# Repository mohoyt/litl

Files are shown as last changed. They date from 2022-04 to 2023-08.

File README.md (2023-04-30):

# litl
Litl is an easy to build 40% keyboard using only through hole components. It uses a separate microcontroller (like the Pro Micro or Elite C) to enable flexibility in connectivity and to further simplify the soldering experience (no more tricksy USB ports).

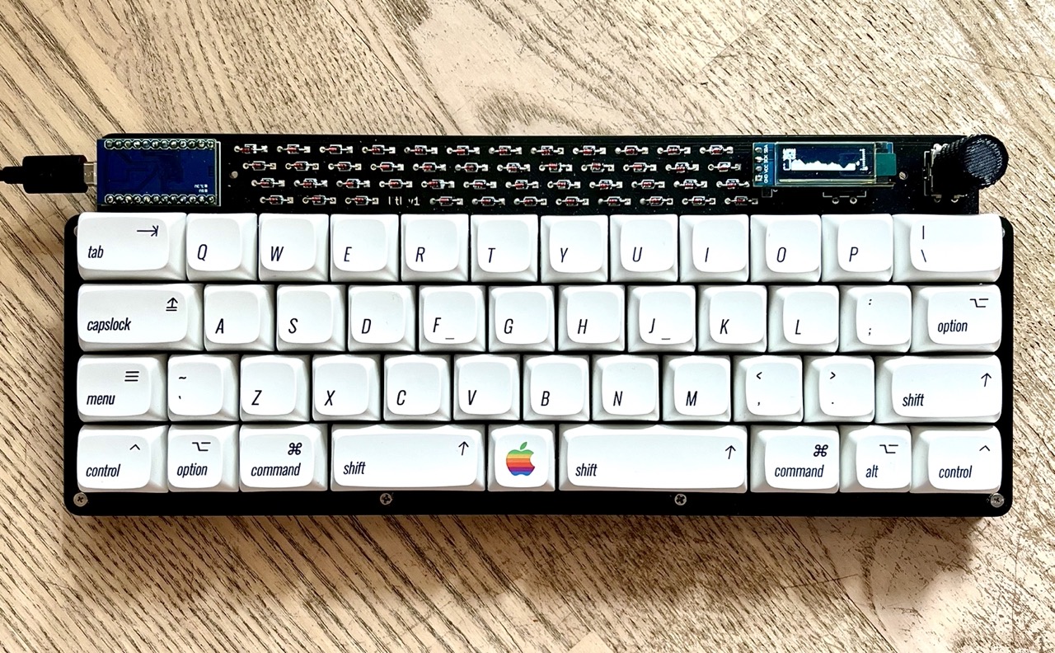
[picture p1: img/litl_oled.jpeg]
litl


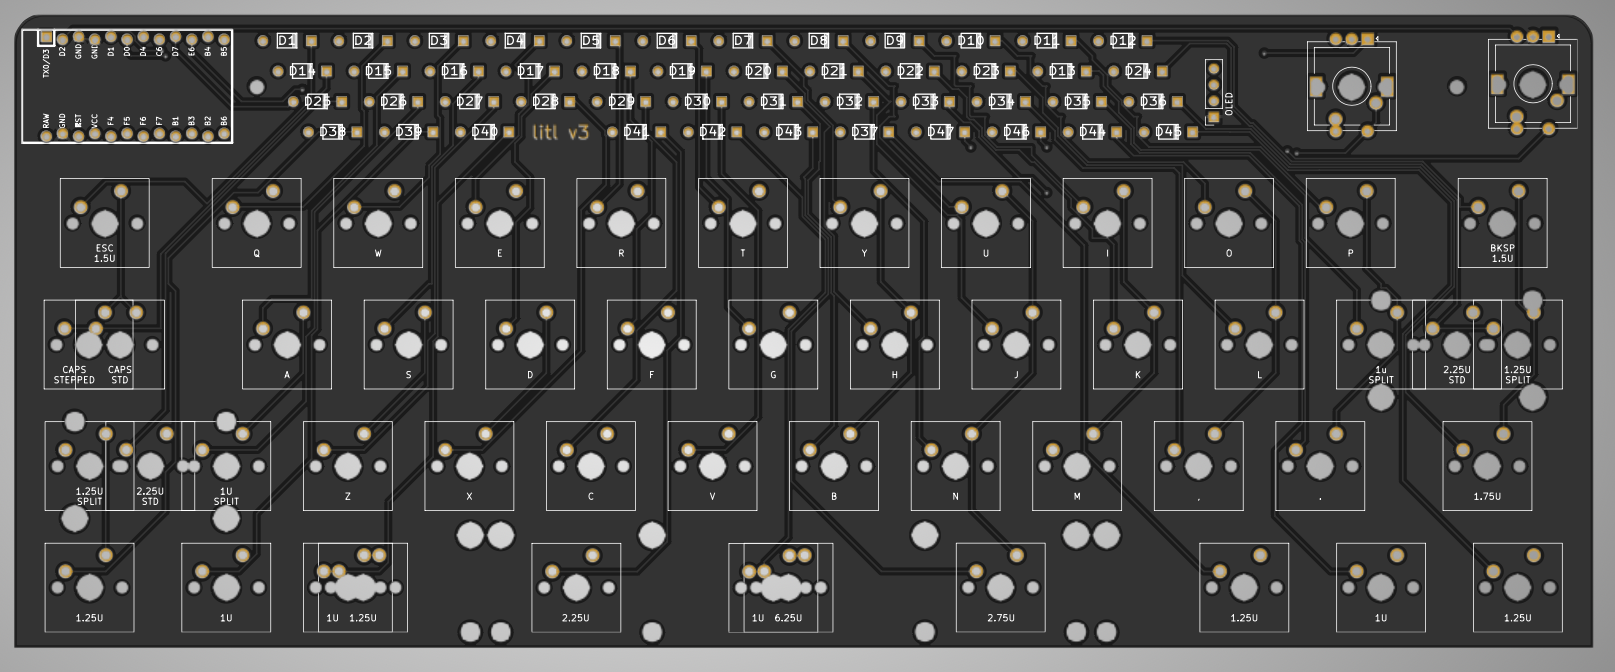
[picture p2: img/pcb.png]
litl pcb


[License](LICENSE)

Litl is licensed under the [Creative Commons Attribution-NonCommercial 4.0 International license](https://creativecommons.org/licenses/by-nc/4.0/). This design as it stands in this repository may be freely reproduced, modified, and manufactured for PERSONAL USE ONLY and may not be reproduced in physical form for public sale. 

Litl kits are available for sale at [sthlmkb.com](https://sthlmkb.com)

## Features
* Only through hole components for easy soldering
* Separate microcontroller using Pro micro, Elite C, Nice! Nano or equivalent footprint. So micro USB, USB-C or Bluetooth are all options!
* 1 or 2 rotary encoders
* OLED screen (though only 1 rotary encoder is possible if using OLED)
* Multiple layout options including split space (2.25u + 1u + 2.75u), split left shift (1.25u + 1u), split enter (1u + 1.25u) and stepped capslock ([layout](http://www.keyboard-layout-editor.com/##@_name=litl&author=mohoyt;&@_x:10.75&c=#82e0f5;&=Enc%202&_x:0.25&w:2.25;&=OLED&_x:0.25&c=#cccccc;&=Enc;&@_y:0.25&x:2.5&w:1.5;&=Esc&=Q&=W&=E&=R&=T&=Y&=U&=I&=O&=P&_w:1.5;&=Back%3Cbr%3ESpace;&@_c=#ebbebe&w:1.25&w2:1.75&l:true;&=Tab&_x:1.25&w:1.75;&=Tab&_c=#cccccc;&=A&=S&=D&=F&=G&=H&=J&=K&=L&_c=#aee6cb&w:2.25;&=Enter;&@_c=#dfe6ba&w:2.25;&=Shift&_x:0.25&w:1.25;&=Shift&=%60%0A~&_c=#cccccc;&=Z&=X&=C&=V&=B&=N&=M&=%3C%0A,&=%3E%0A.&_w:1.75;&=Shift;&@_x:2.5&w:1.25;&=Ctrl&=Alt&_c=#a8abed&w:1.25;&=Cmd&_a:7&w:2.25;&=&_a:4;&=Super&_a:7&w:2.75;&=&_c=#cccccc&a:4&w:1.25;&=Cmd&=Alt&_w:1.25;&=Ctrl;&@_y:0.25&x:4.75&c=#a8abed;&=Cmd&_a:7&w:6.25;&=&_x:1.25&c=#aee6cb&a:4;&='%0A%22&_w:1.25;&=Enter"))
* Open and visible components (in the style of Plaid, Romac etc)
* Simple and flexible case options 

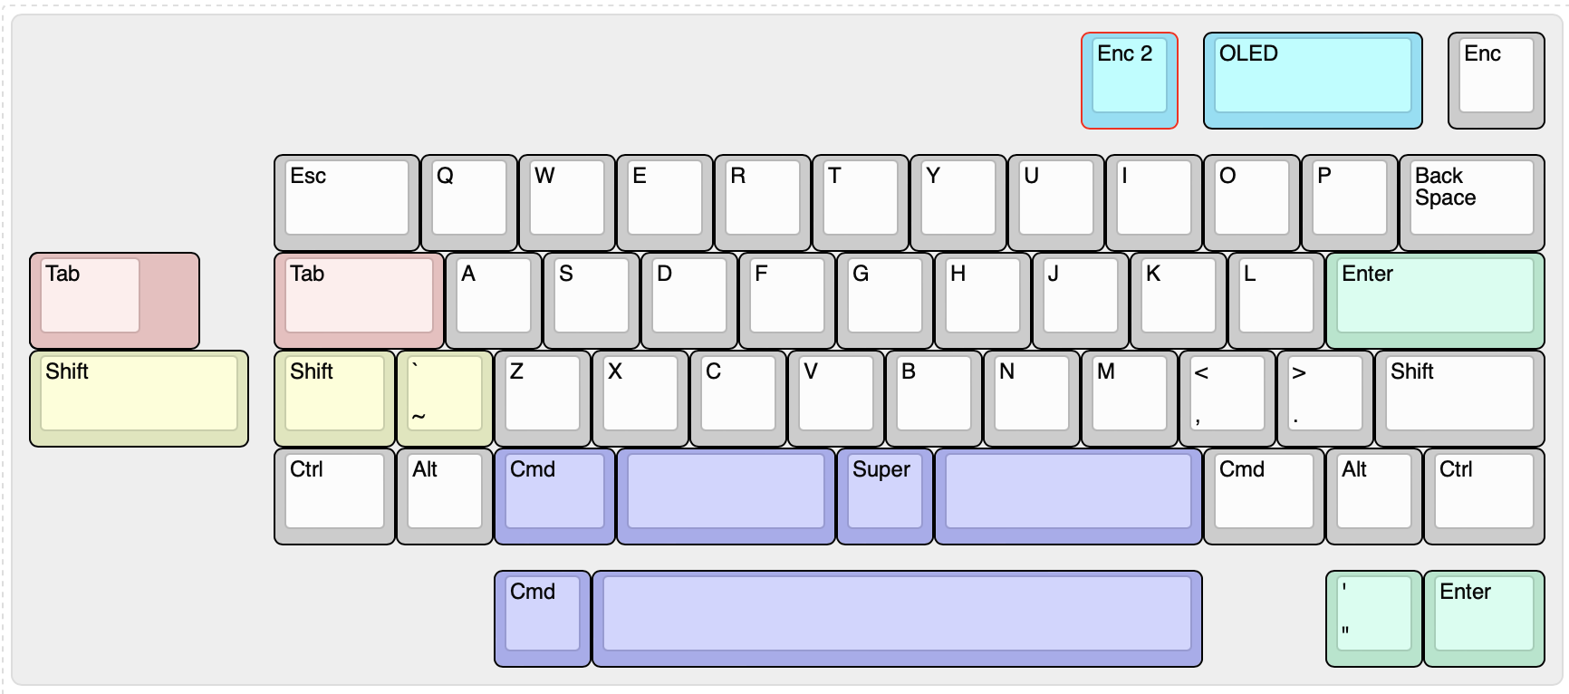
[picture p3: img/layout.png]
litl layout


## Components required 
* PCB
* FR4 Switch plate
* FR4 Base 
* Controller (e.g. Pro micro, Elite C, Nice! Nano or something with similar footprint/pinout)
* Switches (5 pin MX footprint) (up to 45)
* Diodes (47)
* Rotary encoders (1 or 2)
* Rotary encoder knobs (1 or 2)
* 0.91" OLED screen 
* 10mm M2 Standoffs (6 required if mounting the base to the plate)
* Acrylic cover for the components at the top (optional)
* Stabilisers (PCB mount) (4 x 2u or 2 x 2u + 6.25u or 2 x 2u depending on layout)
* Rubber feet for the base

[Build guide](build_guide.md)

## Known issues 
Have been fixed in v2 (and gerbers now updated) but were present in v1
- [x] Esc key is missing holes for 5 pin switches (workaround is to cut the pins off that switch to make it 3 pin and with the plate it will still be stable)
- [x] Track routing goes under the front logo and makes it less clear, needs rerouting slightly
- [x] OLED pins are reversed so the OLED has to be mounted facing left (over the diodes) instead of right

Have been fixed in v3 (and gerbers now updated) but were present in later iterations of v2
- [x] Pin for switch alternative on left rotary encoder shorted with ground
- [x] Holes for optional acrylic cover have been readded

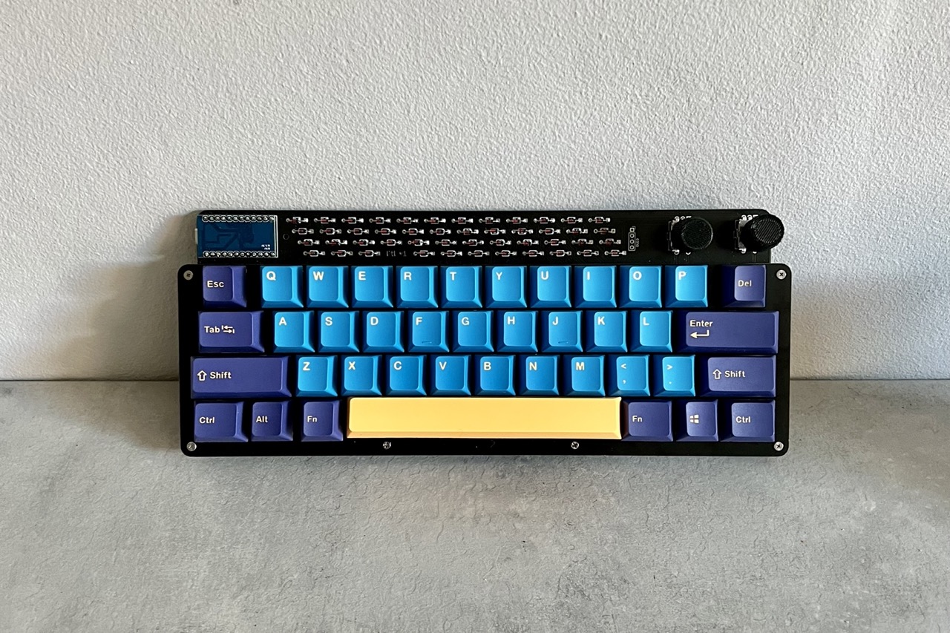
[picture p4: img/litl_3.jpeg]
litl


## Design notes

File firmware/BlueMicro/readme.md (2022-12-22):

These files let you build firmware for litl keyboard when used with a nice!nano board.
source folder contains the files required for use with: https://github.com/jpconstantineau/BlueMicro_Builder

Included an example .uf2 file for testing using default litl keymap.

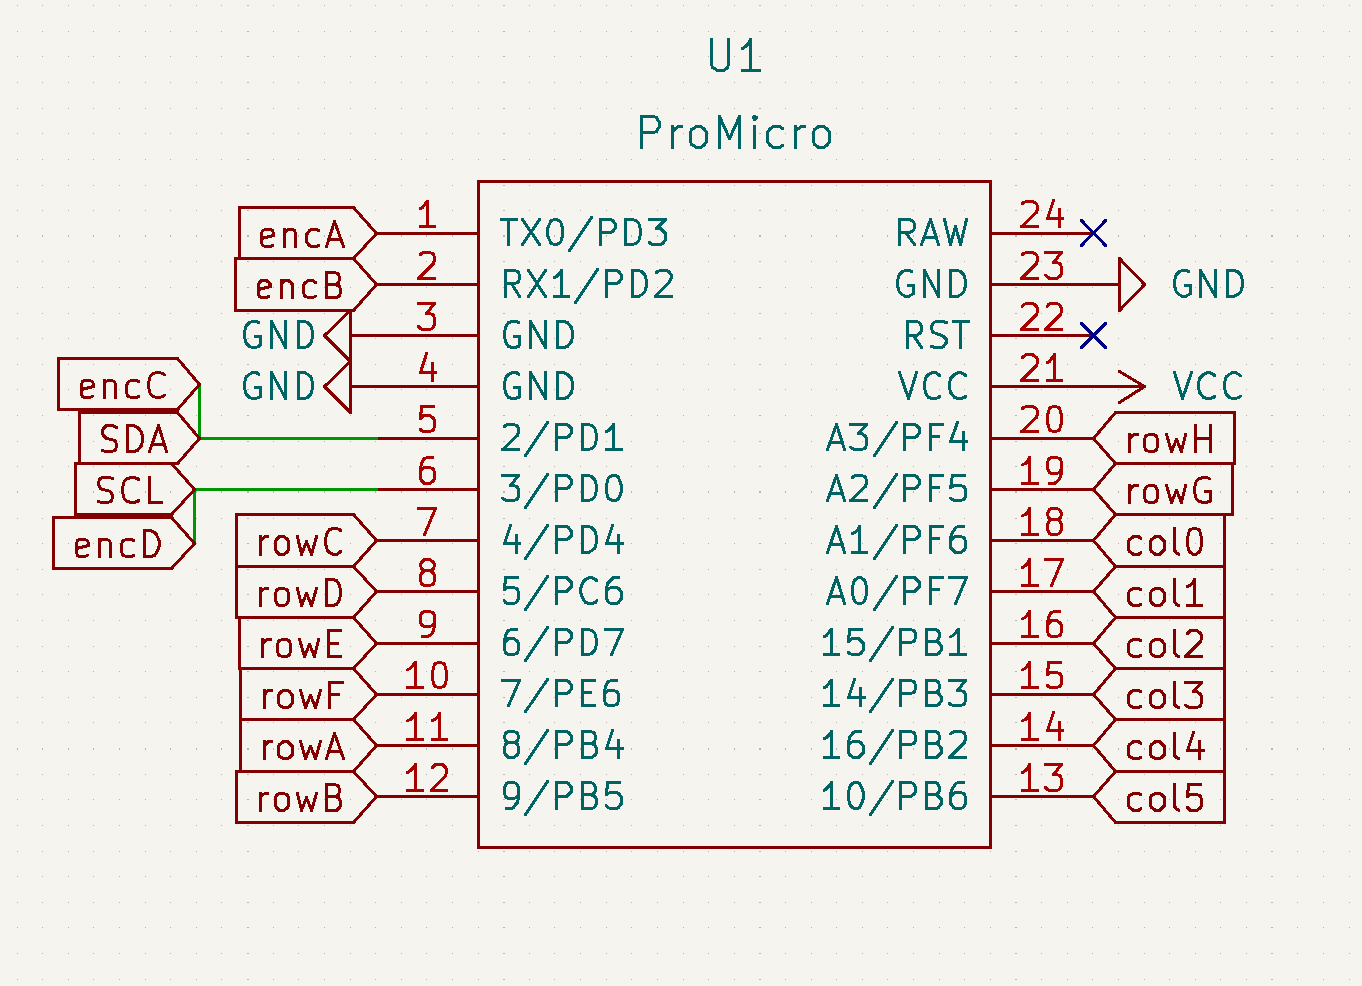
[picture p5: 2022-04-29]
PCB/Pinout.png

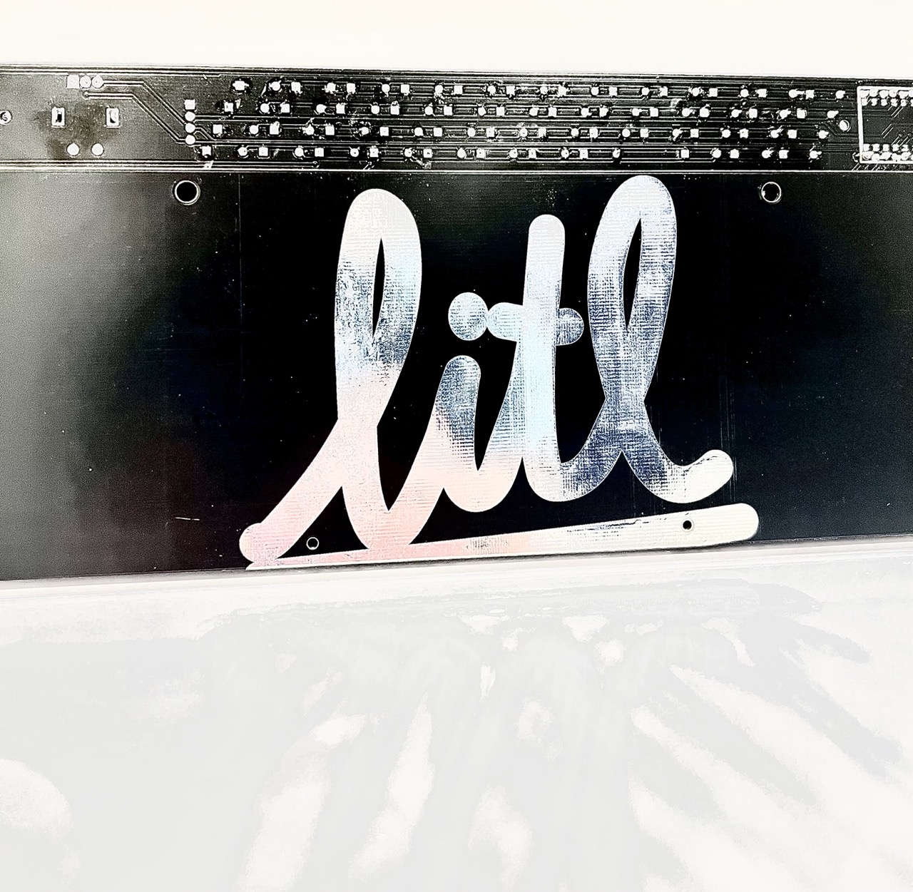
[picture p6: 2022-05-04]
img/back.jpeg

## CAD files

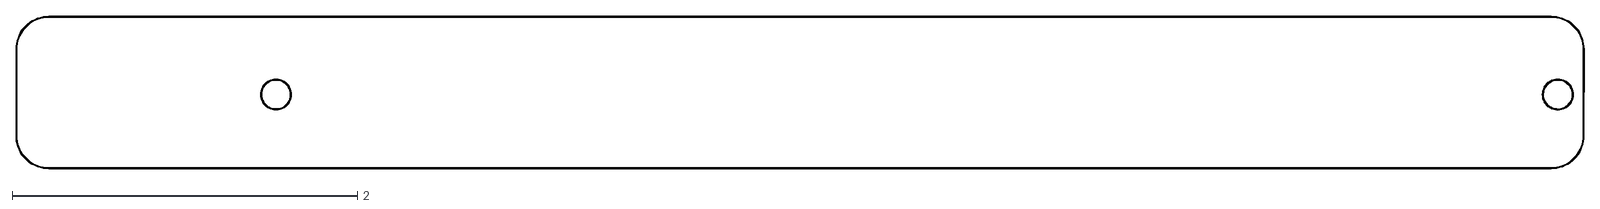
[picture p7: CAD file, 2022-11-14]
PCB/litl_acrylic_guard/Acrylic Guard-Edge_Cuts.dxf
9.08 x 0.881

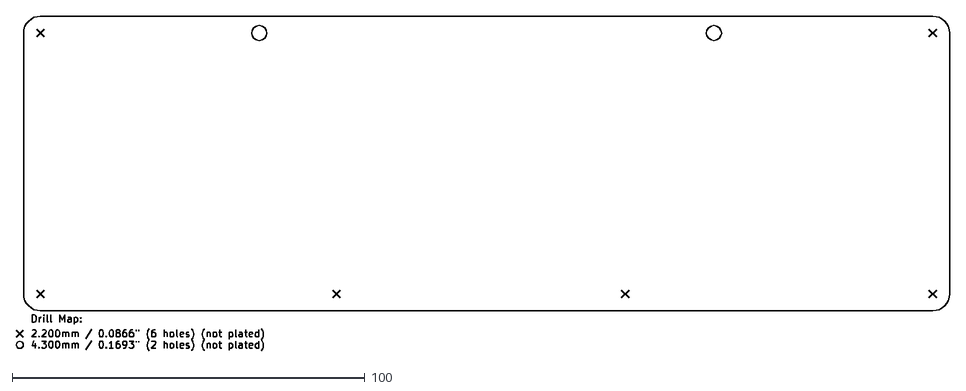
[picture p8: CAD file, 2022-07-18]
PCB/litl_base_2025/gerbers/litl_base-NPTH-drl_map.dxf
264.7 x 94.9

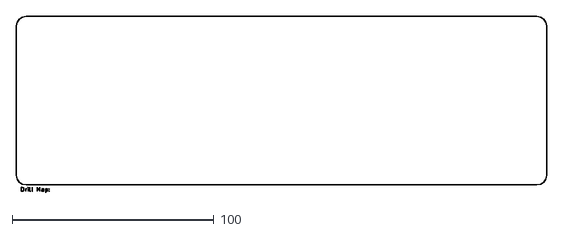
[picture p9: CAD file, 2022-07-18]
PCB/litl_base_2025/gerbers/litl_base-PTH-drl_map.dxf
262.6 x 87.4

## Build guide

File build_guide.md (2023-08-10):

# Litl build guide

## Components required 

* PCB
* FR4 Switch plate
* FR4 Base 
* Controller (I used a pro micro in the guide but anything that shares the footprint and pinout will be fine e.g. Elite C or Nice! Nano)
* Diodes (47)
* Switches (5 pin MX footprint) (up to 45)
* Rotary encoders (1 or 2)
* Rotary encoder knobs (1 or 2)
* 0.91" OLED screen (optional)
* 10mm M2 Standoffs (6 required if mounting the base to the plate)
* 6mm x M2 screws for attaching the standoffs to the plate/base (2 per standoff so 12 total)
* Acrylic cover for the components at the top (optional, not included)
* Stabilisers (PCB mount) (4 x 2u or 2 x 2u + 6.25u or 2 x 2u depending on layout)
* Rubber feet for the base

## You will also need

* Soldering iron
* Solder
* Diode bender (helpful but not required, I used [this one](https://www.printables.com/model/23523-1n4148-diodes-bending-jig))

## Step by step

1. Check that you have all the components you need.
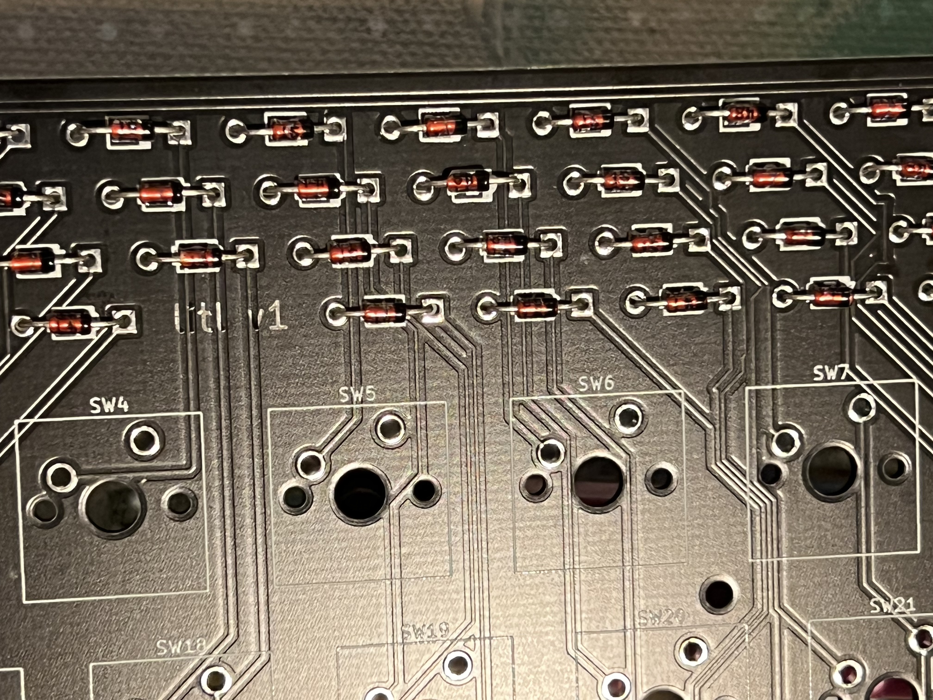
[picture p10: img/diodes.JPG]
diode orientation

2. Start by bending all the diodes (I used the 3d printed diode bender above). And then place them in the sockets, ensuring that you have the *correct orientation*, the black line on the diode should match the white lines on the board. I then placed some tape over the diodes to hold them in place while I flipped over the board to solder them.
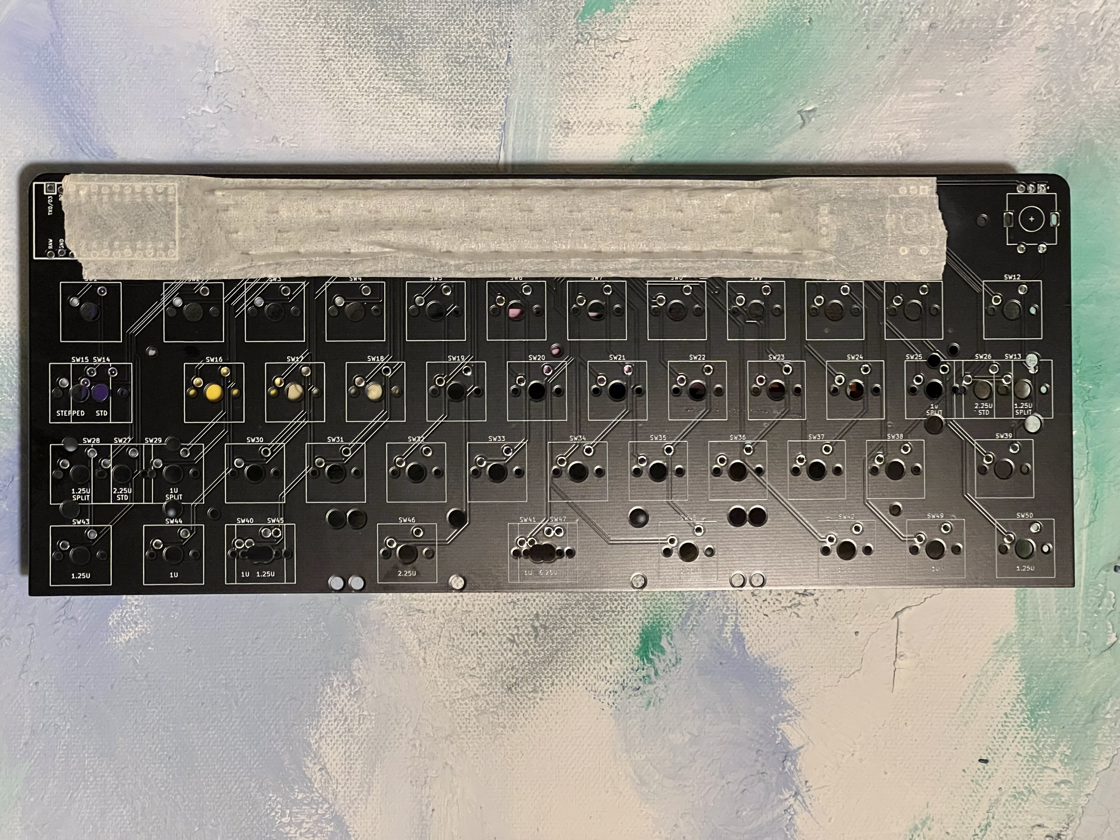
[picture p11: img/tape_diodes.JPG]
diode tape

3. Solder the diodes on (I soldered on the underside of the board) and trim their legs once the solder has cooled
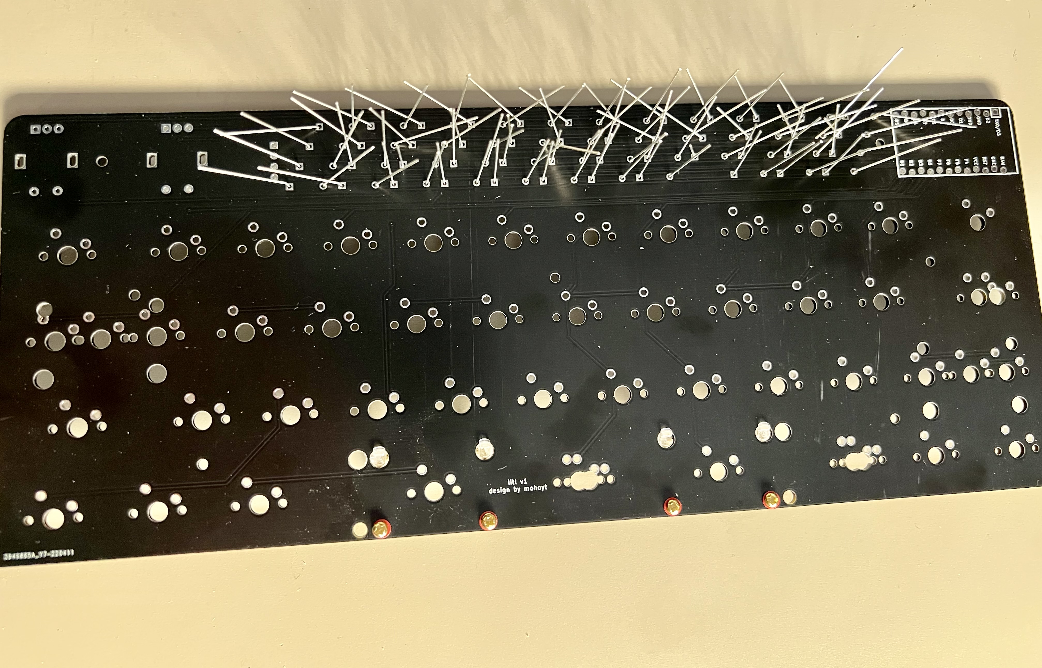
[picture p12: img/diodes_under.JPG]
diode soldering

4. Flash your controller and check that it is working as expected (e.g. when you plug it into the computer it is recognised as a USB keyboard device). See flashing instructions [here](flash_guide.md).
5. Solder your controller to the board. The board has offset holes so that hotswapping might work, but this didn't go so great in practice so I just soldered my controller on. You are of course very welcome to socket your controller too if you value switchability. I soldered headers onto my controller and then soldered everything onto the PCB and then trimmed the legs on the underside of the PCB. *Orientation matters* here so ensure that you have the controller in the right position. 
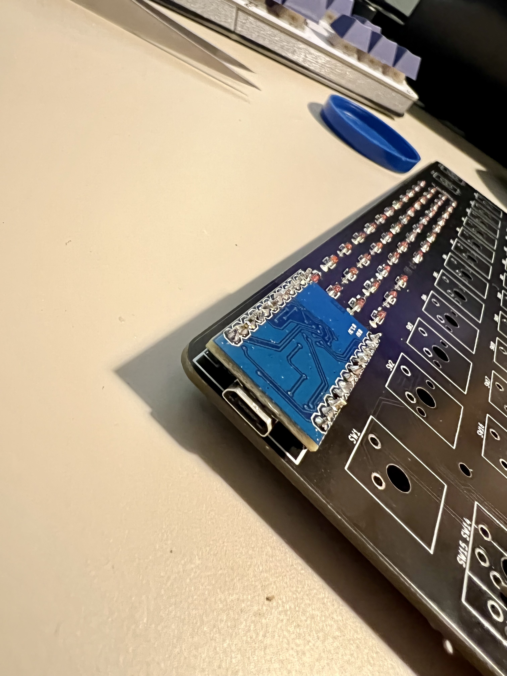
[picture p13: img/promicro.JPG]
pro micro

6. Now you should be able to plug in your board and test that all keystrokes are recognised. I used a pair of tweezers to short the switch sockets for this. 
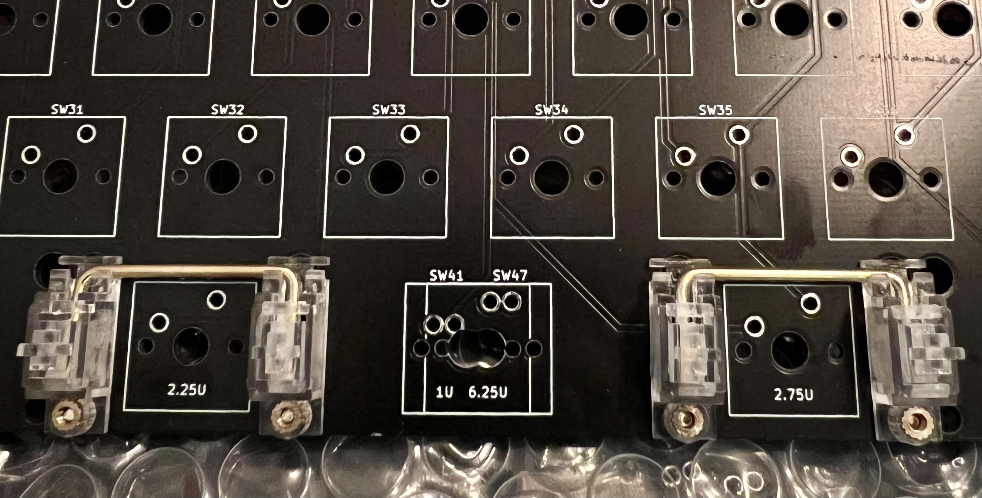
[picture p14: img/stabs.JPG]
stabilisers

7. Add the stabilisers. Hopefully by now you should know what layout you want, but if you don't then now's a good time to choose! I used some PCB mounted screw in stabs in the photos. 
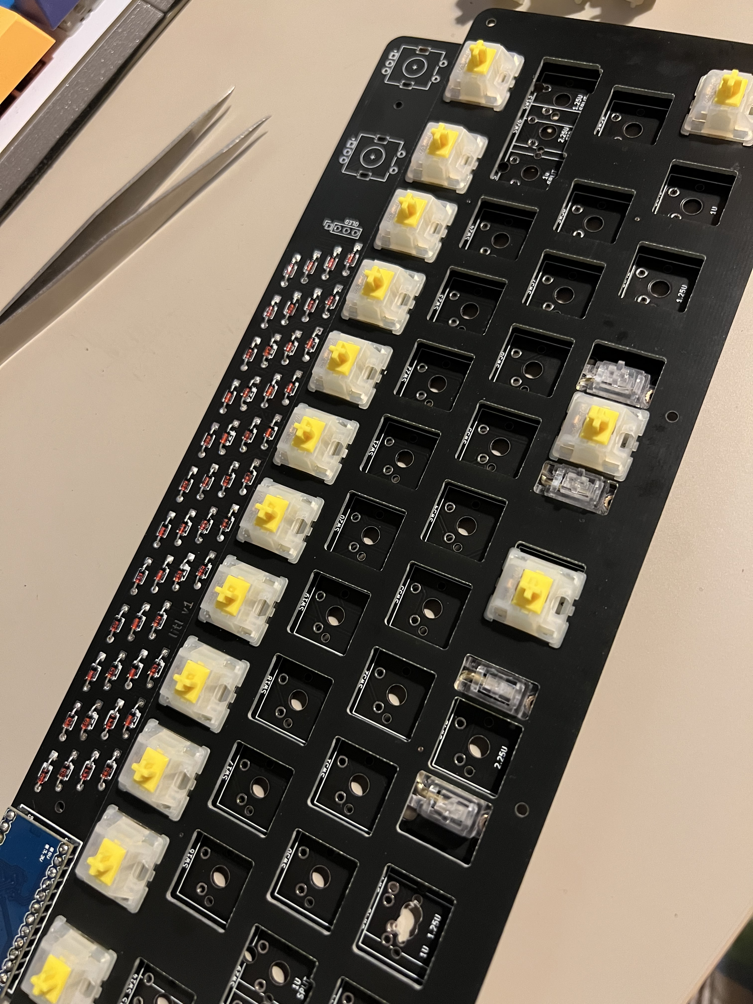
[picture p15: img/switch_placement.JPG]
switch_placement

8. Start by placing a couple switches in the corners of the plate and then attach the plate to the PCB ensuring that you don't bend any pins while doing so. Continue placing the rest of the switches until all keys are present. I used Gateron Pro Yellows in the photos with all of the split options. You cal also add the encoders and the OLED screen at this point if you're going with these options.
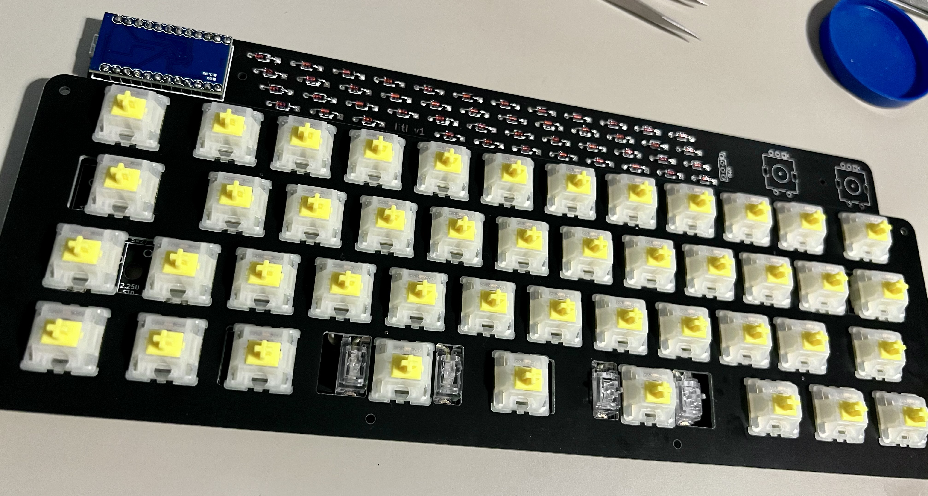
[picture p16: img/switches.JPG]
switches

9. Double check that your stabilisers are all correct (i.e. the wires are seated securely) and lubed as there's no going back once you've soldered switches in. Check again that that none of the switch pins are bent. 
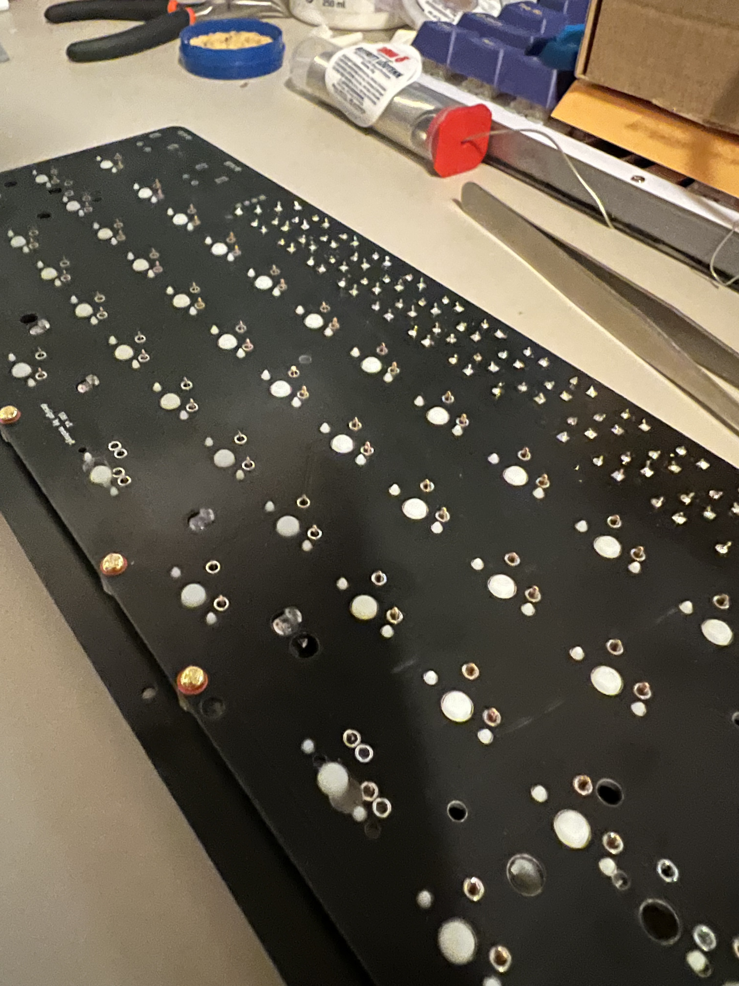
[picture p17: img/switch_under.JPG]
switch_under

10. Start soldering all the switches, OLED and encoders in place. Pay attention to the orientation of the OLED - on Litl v1 the pins are reversed so you will have to mount your OLED screen facing to the left (over the diodes) or manually reverse the pins. The reversed pins are fixed from v2 onwards. Double check that you've not missed anything (it's easy to overlook a few switches).
11. Attach the standoffs to the screws on the edges of the switch plate and position the base plate correctly and screw in the screws from the bottom too. Add the rubber bumbers to the base plate.
12. Add some keycaps and encoder knobs and *you are done!* Have a test that everything's working as expected and maybe update/flash some new firmware if you feel like it. Enjoy!
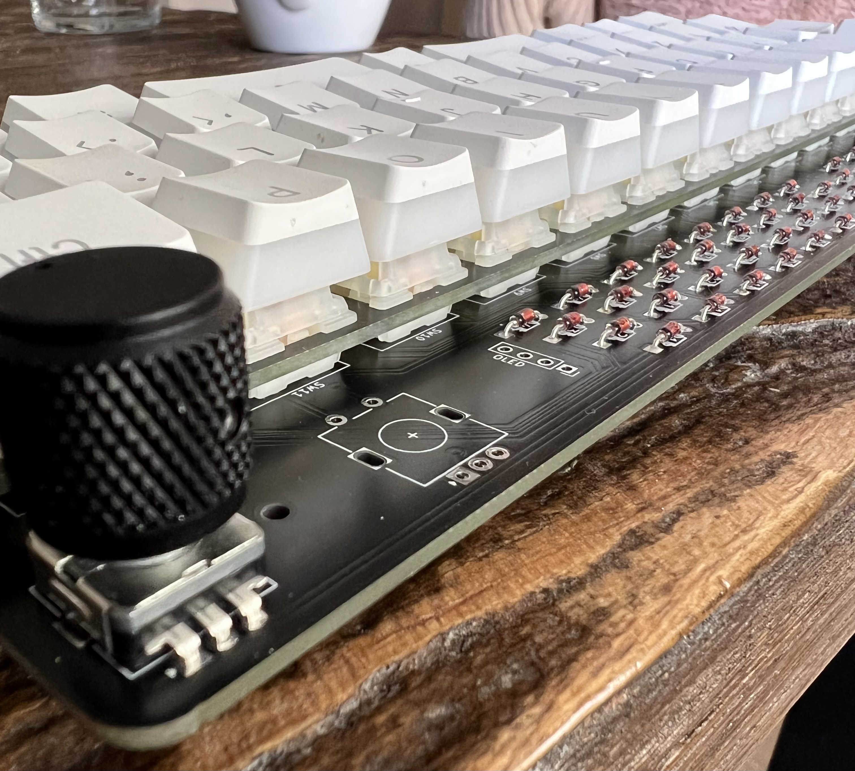
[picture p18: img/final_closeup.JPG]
final_closeup


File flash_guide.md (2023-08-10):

# Pro Micro Microcontroller Flashing Guide

You’ve built your keyboard and now you want to make it work. To do this you’ll have to flash your microcontroller.

The exact specfics of how you do this depend on the microcontroller that you’re using, so take a look at their specific documentation. I will go through the process of flashing a Pro Micro conroller here.

## Step by step

1. You’ll need a compiled firmware file. This is something that you might have downloaded from where you bought your keyboard, or something that you configured and built yourself. It’s a file that has a .hex file format. We have precompiled firmware files for Litl [here](https://github.com/mohoyt/litl/releases).

2. Download and install QMK Toolbox from their Github page: https://github.com/qmk/qmk_toolbox

3. Open QMK Toolbox and connect your keyboard or controller to your computer over USB. You might see something in the QMK console when you connect it, but not always.

4. Press open at the top of the QMK configurator window and choose the .hex file that you want to flash to your microcontroller. Precompiled (and Vial compatible) hex files for the Litl are available [here on our Github](https://github.com/mohoyt/litl/releases). If you want to be able to configure your keyboard using Vial (recommended) then make sure to flash one of the vial hex files. Ensure that the file that you’re trying to flash has the file format .hex as sometimes browsers will download these files oddly. 

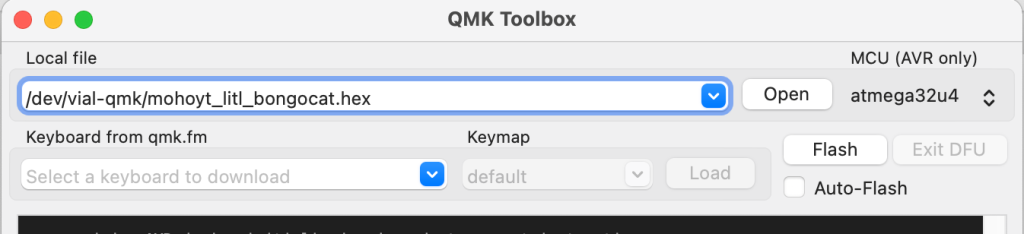
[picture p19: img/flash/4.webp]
qmk toolbox


5. Ensure that you have the correct MCU chosen at the top right of the QMK Toolbox window. For a Pro Micro it is an atmega32u4

6. Now comes the slightly tricky bit. You’ll need something metal to short two of the pins on the microcontroller. You can use pliers, a piece of wire or even a pen. You want to briefly connect and then disconnect the RESET and the GROUND pins of the Pro Micro. These are the second and third pins on the right hand side when the components are facings towards you and the usb port is facing up.

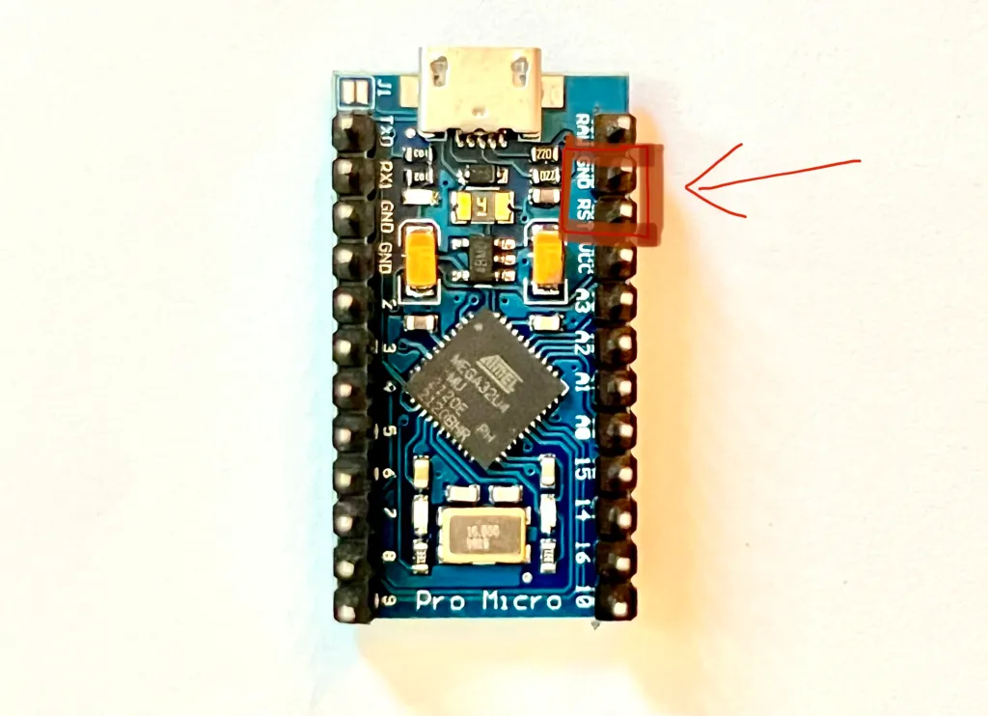
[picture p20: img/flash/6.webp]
pro micro pins


If you’re flashing the controller once it’s already soldered on the keyboard then you will need to short the same pins but likely from the other side. It’s the two pins pictured in the image below.

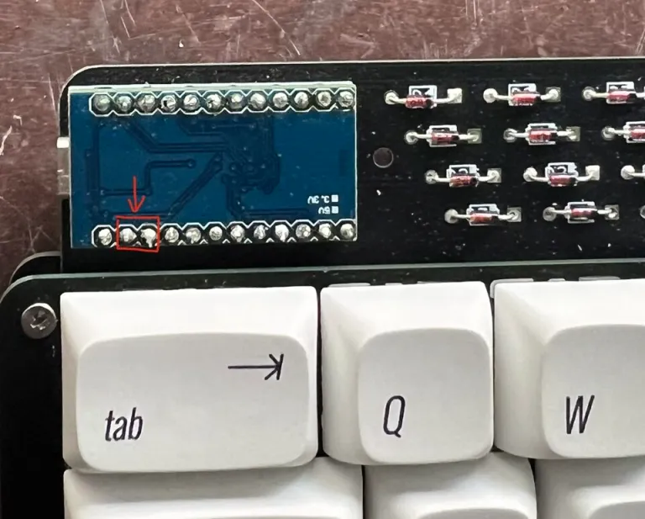
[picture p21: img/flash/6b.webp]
pro micro pins on board


7. If you’ve successfully connected the pins and then disconnected them you should see a yellow line in the QMK Toolbox console like this. The line might say something slightly different depending on your controller.

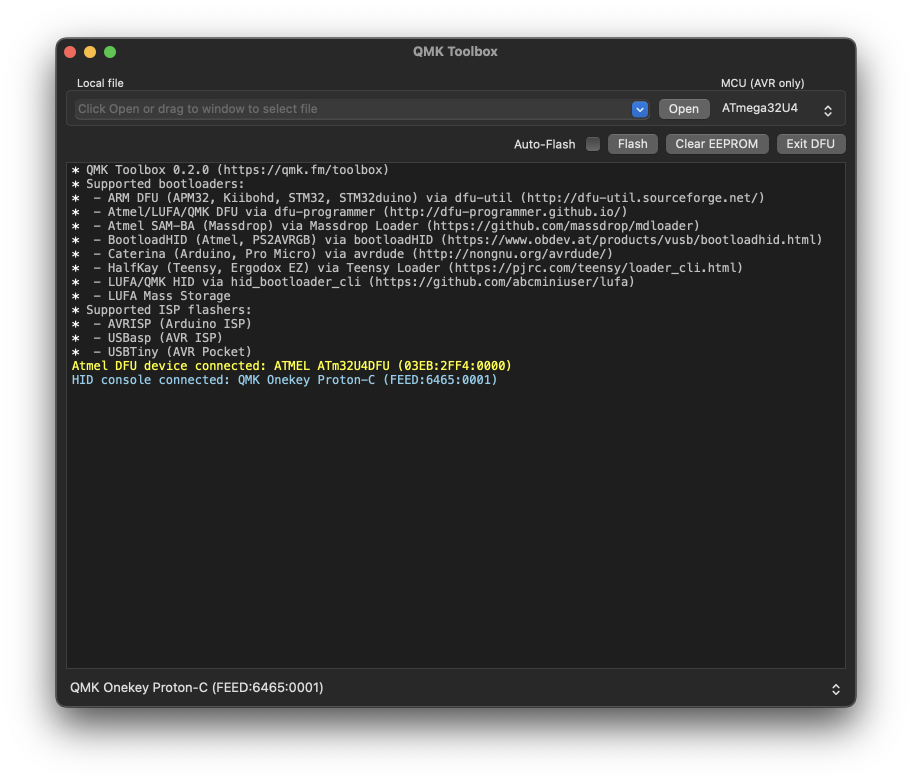
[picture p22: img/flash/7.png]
qmk toolbox screenshot


8. Once you see the yellow line, you need to press Flash within 5 seconds. There will be lots of text rendered on the console when you do this, but it will ultimately say something like avrdude done. Thank you  and then will print another yellow disconnect line if it succeeds.

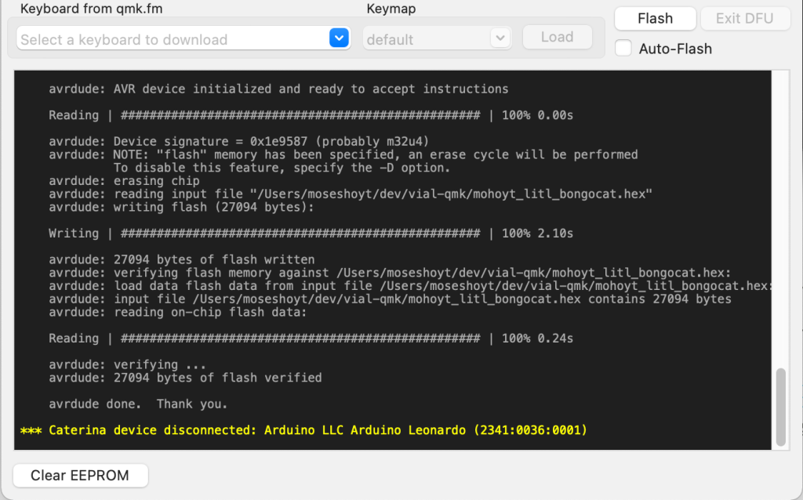
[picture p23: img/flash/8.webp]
successful flash


9. If you’ve flashed the QMK firmware then your keyboard should be good to go right away. If you flashed the Vial firmware then your keyboard should work right away too, but if you want to configure layers then you will have to download Vial.

## You did it! Nice one. 

Any feedback or challenges with the build process? Get in touch with us at hej at sthlmkb.com

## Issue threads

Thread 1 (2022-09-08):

modification of the board for commercial use

worldspawn00, 2022-09-08:
Hi,

Couldn't figure out how to contact you, I'm wanting to sell a version of your litl board in my etsy shop, I made several major modifications to the design, and per your request, I'm asking permission to sell my version of the board! I've attached an image of the updates (added hotswap socket options, added 2nd OLED location, added switch option to 2nd encoder position, added reset button, added optional SMD diode pads, and cleaned up traces significantly).  I've left the design attribution to you on the PCB with a note that it's been modified by myself.  Let me know if I can put this version up on my shop.

Thanks!

Worldspawn00
(you can contact me directly on Discord at Worldspawn#0110)

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

mohoyt, 2022-10-05:
Hey Worldspawn00!

Sorry for the delay in getting back to you! My GitHub notifications are off so I didn't notice this until today. I like the modifications and changes that you've made to the board! Would you consider sharing a small amount of proceeds from each sale of the board, and limiting your sales of the board to the Americas? If so, then I'd be happy for you to sell your version.

Thanks again!
mohoyt (also on Discord at mojibber#1632)

EzioFenix, 2022-11-24:
I used your keyboard layout, but I have little doubts about, when you want to change from a large enter key to two keys, what do you change? Do you only put the switches according to your layout and what do you modify in the code?

I feel that the documentation lacks distribution, documentation and other inconveniences, I would like to work with you to improve it and make a distribution for the Spanish language devorak programmer, and publish it in your repository.

worldspawn00, 2022-11-24:
> I used your keyboard layout, but I have little doubts about, when you want to change from a large enter key to two keys, what do you change? Do you only put the switches according to your layout and what do you modify in the code?

The extra key beside the enter is needed for some international (any layout that uses ISO enter) and non-standard layouts, it's part of the home row and gets a lot of use as a typing key, so it's nice to have an option to place an extra switch there between the L and Enter keys.

Code modification is simple, as the position already exists in the original matrix (even though it's not used/assigned), the only extra step is adding it into the layout.

Closed 2024-03-25.

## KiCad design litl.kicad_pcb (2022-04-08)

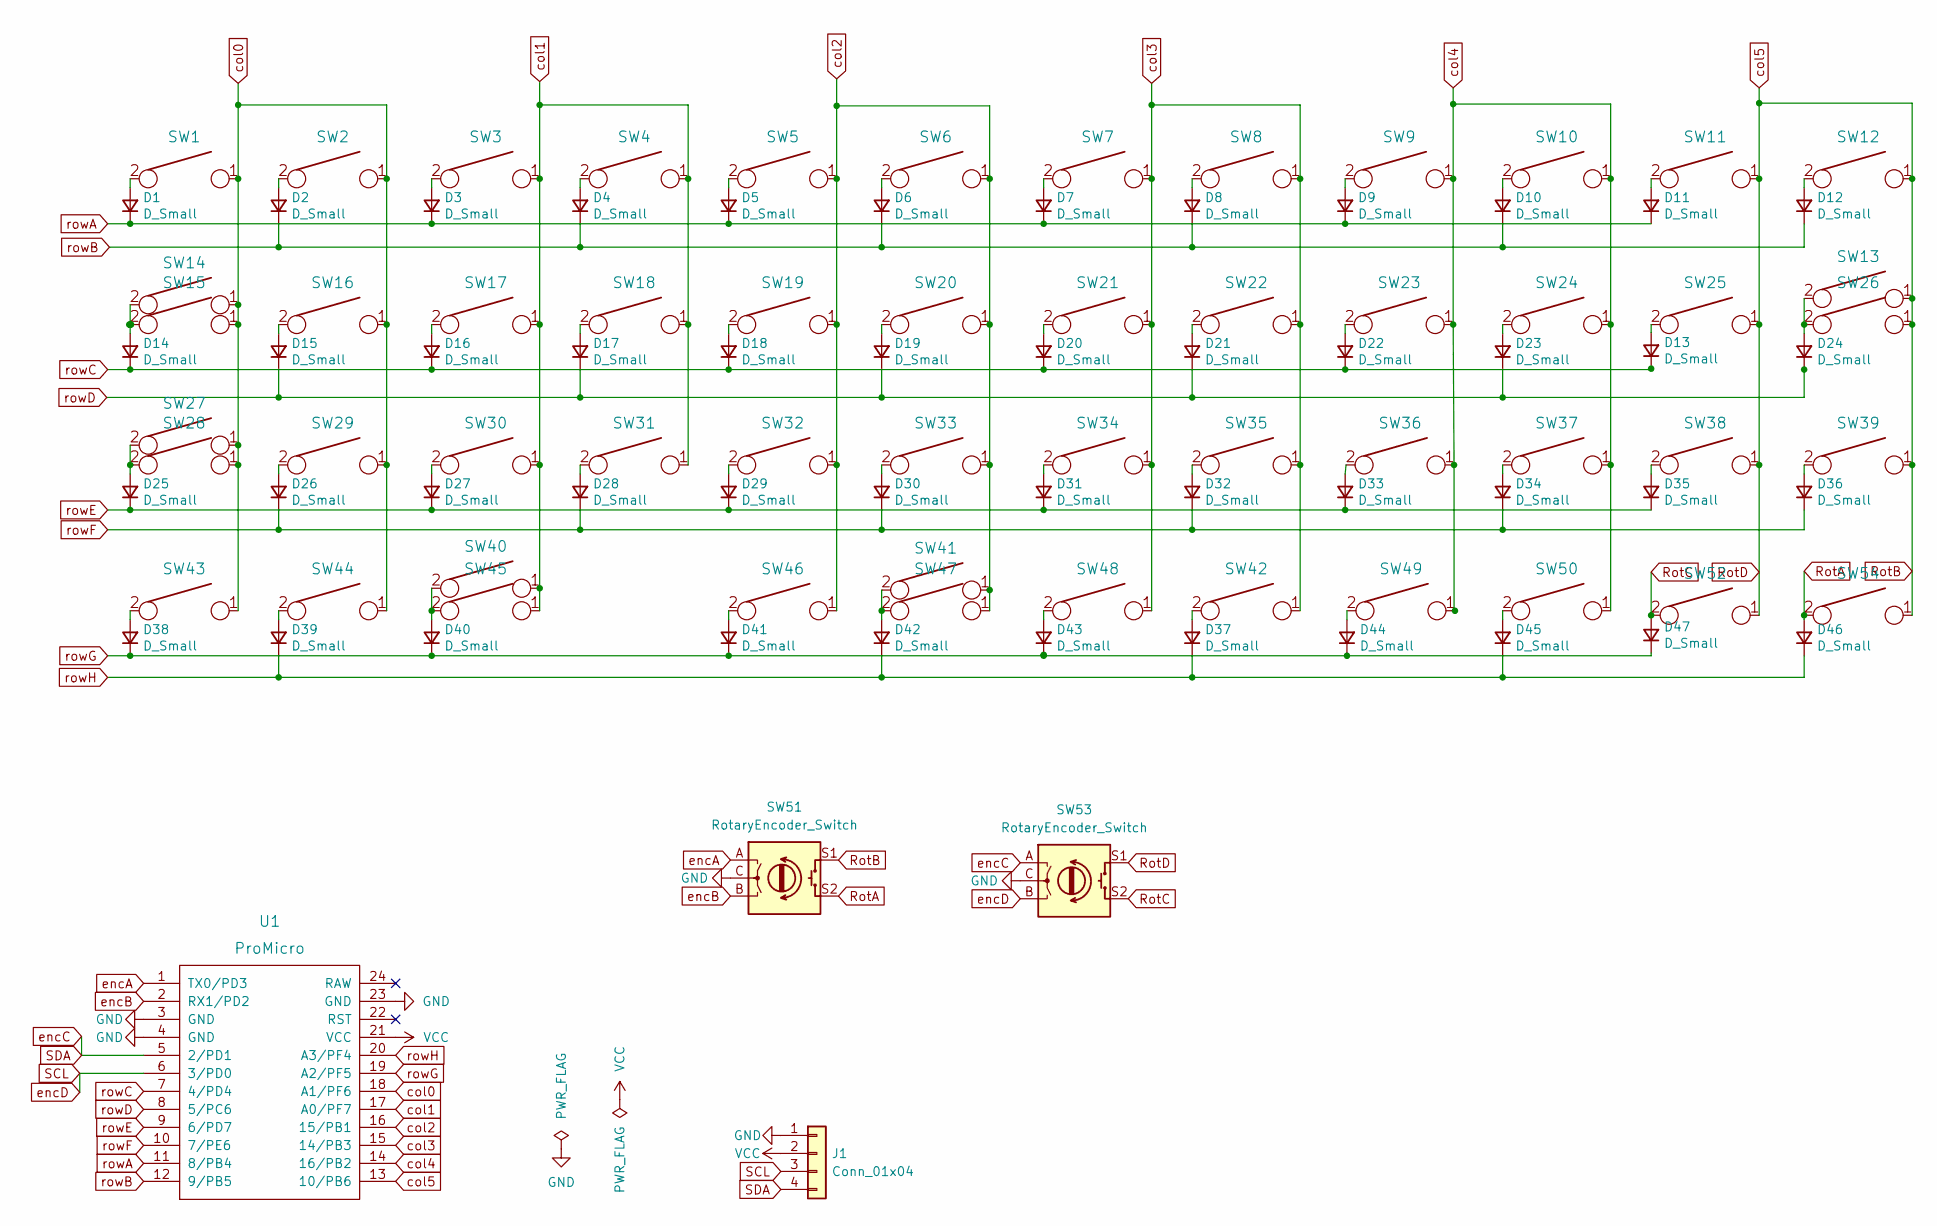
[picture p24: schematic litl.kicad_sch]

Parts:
D1, D2, D3, D4, D5, D6, D7, D8, D9, D10, D11, D12, D13, D14, D15, D16, D17, D18, D19, D20, D21, D22, D23, D24, D25, D26, D27, D28, D29, D30, D31, D32, D33, D34, D35, D36, D37, D38, D39, D40, D41, D42, D43, D44, D45, D46, D47: D_Small; Diode
J1: Conn_01x04; PinSocket_1x04_P2.54mm_Vertical
SW1: KEYSW; SW_Cherry_MX_1.50u_Plate
SW2, SW3, SW4, SW5, SW6, SW7, SW8, SW9, SW10, SW11, SW15, SW16, SW17, SW18, SW19, SW20, SW21, SW22, SW23, SW24, SW25, SW29, SW30, SW31, SW32, SW33, SW34, SW35, SW36, SW37, SW38, SW40, SW41, SW44, SW49: KEYSW; SW_Cherry_MX_1.00u_PCB
SW12: KEYSW; SW_Cherry_MX_1.50u_PCB
SW13, SW28, SW42, SW43, SW45, SW50, SW52, SW54: KEYSW; SW_Cherry_MX_1.25u_PCB
SW14, SW39: KEYSW; SW_Cherry_MX_1.75u_PCB
SW26, SW27, SW46: KEYSW; SW_Cherry_MX_2.25u_PCB
SW47: KEYSW; SW_Cherry_MX_6.25u_PCB
SW48: KEYSW; SW_Cherry_MX_2.75u_PCB
SW51, SW53: RotaryEncoder_Switch; RotaryEncoder_EC11
U1: ProMicro; ArduinoProMicro-ZigZag

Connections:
GND: J1.1, SW51.C, SW53.C, U1.3 (GND), U1.4 (GND), U1.23 (GND)
unnamed: D1.2 (A), SW1.2
unnamed: D2.2 (A), SW2.2
unnamed: D3.2 (A), SW3.2
unnamed: D4.2 (A), SW4.2
unnamed: D5.2 (A), SW5.2
unnamed: D6.2 (A), SW6.2
unnamed: D7.2 (A), SW7.2
unnamed: D8.2 (A), SW8.2
unnamed: D9.2 (A), SW9.2
unnamed: D10.2 (A), SW10.2
unnamed: D11.2 (A), SW11.2
unnamed: D12.2 (A), SW12.2
unnamed: D13.2 (A), SW25.2
unnamed: D14.2 (A), SW14.2, SW15.2
unnamed: D15.2 (A), SW16.2
unnamed: D16.2 (A), SW17.2
unnamed: D17.2 (A), SW18.2
unnamed: D18.2 (A), SW19.2
unnamed: D19.2 (A), SW20.2
unnamed: D20.2 (A), SW21.2
unnamed: D21.2 (A), SW22.2
unnamed: D22.2 (A), SW23.2
unnamed: D23.2 (A), SW24.2
unnamed: D24.2 (A), SW13.2, SW26.2
unnamed: D25.2 (A), SW27.2, SW28.2
unnamed: D26.2 (A), SW29.2
unnamed: D27.2 (A), SW30.2
unnamed: D28.2 (A), SW31.2
unnamed: D29.2 (A), SW32.2
unnamed: D30.2 (A), SW33.2
unnamed: D31.2 (A), SW34.2
unnamed: D32.2 (A), SW35.2
unnamed: D33.2 (A), SW36.2
unnamed: D34.2 (A), SW37.2
unnamed: D35.2 (A), SW38.2
unnamed: D36.2 (A), SW39.2
unnamed: D37.2 (A), SW42.2
unnamed: D38.2 (A), SW43.2
unnamed: D39.2 (A), SW44.2
unnamed: D40.2 (A), SW40.2, SW45.2
unnamed: D41.2 (A), SW46.2
unnamed: D42.2 (A), SW41.2, SW47.2
unnamed: D43.2 (A), SW48.2
unnamed: D44.2 (A), SW49.2
unnamed: D45.2 (A), SW50.2
SCL: J1.3, SW53.B, U1.6 (3/PD0)
SDA: J1.4, SW53.A, U1.5 (2/PD1)
VCC: J1.2, U1.21 (VCC)
col0: SW1.1, SW2.1, SW14.1, SW15.1, SW16.1, SW27.1, SW28.1, SW29.1, SW43.1, SW44.1, U1.18 (A1/PF6)
col1: SW3.1, SW4.1, SW17.1, SW18.1, SW30.1, SW31.1, SW40.1, SW45.1, U1.17 (A0/PF7)
col2: SW5.1, SW6.1, SW19.1, SW20.1, SW32.1, SW33.1, SW41.1, SW46.1, SW47.1, U1.16 (15/PB1)
col3: SW7.1, SW8.1, SW21.1, SW22.1, SW34.1, SW35.1, SW42.1, SW48.1, U1.15 (14/PB3)
col4: SW9.1, SW10.1, SW23.1, SW24.1, SW36.1, SW37.1, SW49.1, SW50.1, U1.14 (16/PB2)
encA: SW51.A, U1.1 (TX0/PD3)
encB: SW51.B, U1.2 (RX1/PD2)
rowA: D1.1 (K), D3.1 (K), D5.1 (K), D7.1 (K), D9.1 (K), D11.1 (K), U1.11 (8/PB4)
rowB: D2.1 (K), D4.1 (K), D6.1 (K), D8.1 (K), D10.1 (K), D12.1 (K), U1.12 (9/PB5)
rowC: D13.1 (K), D14.1 (K), D16.1 (K), D18.1 (K), D20.1 (K), D22.1 (K), U1.7 (4/PD4)
rowD: D15.1 (K), D17.1 (K), D19.1 (K), D21.1 (K), D23.1 (K), D24.1 (K), U1.8 (5/PC6)
rowE: D25.1 (K), D27.1 (K), D29.1 (K), D31.1 (K), D33.1 (K), D35.1 (K), U1.9 (6/PD7)
rowF: D26.1 (K), D28.1 (K), D30.1 (K), D32.1 (K), D34.1 (K), D36.1 (K), U1.10 (7/PE6)
rowG: D38.1 (K), D40.1 (K), D41.1 (K), D43.1 (K), D44.1 (K), D47.1 (K), U1.19 (A2/PF5)
rowH: D37.1 (K), D39.1 (K), D42.1 (K), D45.1 (K), D46.1 (K), U1.20 (A3/PF4)

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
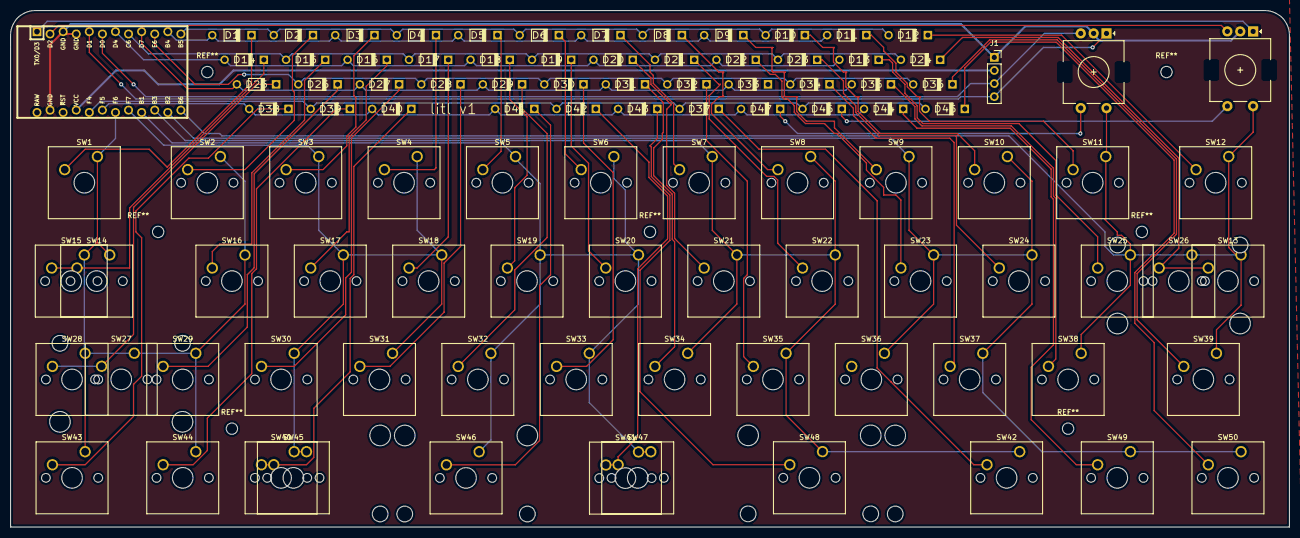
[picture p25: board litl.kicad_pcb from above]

Board: 2 copper layers, 248.3 x 100.3 mm, 101 parts (1 on the bottom side), 67 nets.

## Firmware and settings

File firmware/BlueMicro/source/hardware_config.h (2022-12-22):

/*
Copyright 2020-2021 <Pierre Constantineau>
3-Clause BSD License
Redistribution and use in source and binary forms, with or without modification, are permitted provided that the following conditions are met:
1. Redistributions of source code must retain the above copyright notice, this list of conditions and the following disclaimer.
2. Redistributions in binary form must reproduce the above copyright notice, this list of conditions and the following disclaimer in the documentation and/or other materials provided with the distribution.
3. Neither the name of the copyright holder nor the names of its contributors may be used to endorse or promote products derived from this software without specific prior written permission.
THIS SOFTWARE IS PROVIDED BY THE COPYRIGHT HOLDERS AND CONTRIBUTORS "AS IS" AND ANY EXPRESS OR IMPLIED WARRANTIES, INCLUDING, BUT NOT LIMITED TO, THE IMPLIED WARRANTIES OF MERCHANTABILITY AND FITNESS FOR 
A PARTICULAR PURPOSE ARE DISCLAIMED. IN NO EVENT SHALL THE COPYRIGHT HOLDER OR CONTRIBUTORS BE LIABLE FOR ANY DIRECT, INDIRECT, INCIDENTAL, SPECIAL, EXEMPLARY, OR CONSEQUENTIAL DAMAGES (INCLUDING, BUT NOT 
LIMITED TO, PROCUREMENT OF SUBSTITUTE GOODS OR SERVICES; LOSS OF USE, DATA, OR PROFITS; OR BUSINESS INTERRUPTION) HOWEVER CAUSED AND ON ANY THEORY OF LIABILITY, WHETHER IN CONTRACT, STRICT LIABILITY, OR TORT 
(INCLUDING NEGLIGENCE OR OTHERWISE) ARISING IN ANY WAY OUT OF THE USE OF THIS SOFTWARE, EVEN IF ADVISED OF THE POSSIBILITY OF SUCH DAMAGE.
*/
#ifndef HARDWARE_CONFIG_H
#define HARDWARE_CONFIG_H
#include "hardware_variants.h"

/* HARDWARE DEFINITION*/
/* key matrix size */
#define MATRIX_ROWS 8
#define MATRIX_COLS 6

#define MATRIX_ROW_PINS {36, 38, 22, 24, 32, 11, 29, 31 }
#define MATRIX_COL_PINS {2, 47, 45, 43, 10, 9 }
#define UNUSED_PINS {}

/* COL2ROW or ROW2COL */
#define DIODE_DIRECTION ROW2COL
#define BATTERY_TYPE BATT_LIPO
#define VBAT_PIN  4

#define VCC_PIN 13
#define VCC_POLARITY_ON 1

#define STATUS_BLE_LED_PIN  15  
#define BLE_LED_ACTIVE 1

#define ENCODER_A_PIN  6 
#define ENCODER_B_PIN  8
#define ENCODER_RESOLUTION 2  
    
#endif /* HARDWARE_CONFIG_H */

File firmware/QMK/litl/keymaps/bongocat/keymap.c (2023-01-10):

/* Copyright 2022 mohoyt
 *
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
 * You should have received a copy of the GNU General Public License
 * along with this program.  If not, see <http://www.gnu.org/licenses/>.
 */
#include QMK_KEYBOARD_H
#include <stdio.h>

// OLED setup for bongocat
#define IDLE_FRAMES 5
#define IDLE_SPEED 30
#define TAP_FRAMES 2
#define TAP_SPEED 40
#define ANIM_FRAME_DURATION 200
#define ANIM_SIZE 512

static long int oled_timeout = 600000; // 10 minutes
bool gui_on = true;
char wpm_str[10];
uint32_t anim_timer = 0;
uint32_t anim_sleep = 0;
uint8_t current_idle_frame = 0;
uint8_t current_tap_frame = 0;

const uint16_t PROGMEM keymaps[][MATRIX_ROWS][MATRIX_COLS] = {
  [0] = LAYOUT_all(
      KC_ESC, KC_Q, KC_W, KC_E, KC_R, KC_T, KC_Y, KC_U, KC_I, KC_O, KC_P, KC_BSPC,
      KC_TAB, KC_A, KC_S, KC_D, KC_F, KC_G, KC_H, KC_J, KC_K, KC_L, KC_SCLN, KC_ENT,
      LSFT_T(KC_GRV), KC_SLSH, KC_Z, KC_X, KC_C, KC_V, KC_B, KC_N, KC_M, KC_COMM, KC_DOT, KC_RSFT,
      KC_LCTL, KC_LGUI, KC_LALT, LT(1, KC_SPC), MO(2), LT(1, KC_SPC), KC_RALT, KC_RGUI, KC_RCTL, KC_MPLY, KC_MUTE ),

  [1] = LAYOUT_all(
  	  KC_ESC, KC_1, KC_2, KC_3, KC_4, KC_5, KC_6, KC_7, KC_8, KC_9, KC_0, KC_BSPC,
  	  KC_TRNS, KC_TRNS, KC_TRNS, KC_TRNS, KC_TRNS, KC_TRNS, KC_UP, KC_UP, KC_MINS, KC_EQL, KC_QUOT, KC_ENT,
  	  KC_TRNS, KC_TRNS, KC_TRNS, KC_TRNS, KC_TRNS, KC_TRNS, KC_LEFT, KC_DOWN, KC_RIGHT, KC_EQL, KC_SLSH, KC_TRNS,
  	  KC_TRNS, KC_TRNS, KC_TRNS, KC_TRNS, KC_TRNS, KC_TRNS, KC_TRNS, KC_TRNS, KC_TRNS, KC_MPLY, KC_MUTE ),

  [2] = LAYOUT_all(
      KC_TRNS, RGB_SAI, RGB_SAD, KC_TRNS, KC_TRNS, KC_TRNS, KC_TRNS, KC_NO  , KC_UP, KC_TRNS, KC_TRNS, KC_TRNS,
      KC_TRNS, RGB_TOG, RGB_MOD, RGB_RMOD,KC_TRNS, KC_TRNS, KC_NO  , KC_LEFT, KC_DOWN, KC_RIGHT, KC_TRNS, KC_TRNS,
      KC_TRNS, RGB_VAI, RGB_VAD, KC_TRNS, KC_TRNS, KC_TRNS, KC_TRNS, KC_TRNS, KC_TRNS, KC_TRNS, KC_UP, KC_UP,
      KC_TRNS, KC_TRNS, KC_TRNS, KC_TRNS, KC_TRNS, KC_TRNS, KC_LEFT, KC_DOWN, KC_RIGHT, KC_TRNS, KC_TRNS )
};

//Encoder map
#if defined(ENCODER_MAP_ENABLE)
const uint16_t PROGMEM encoder_map[][1][2] = {
    [0] =   { ENCODER_CCW_CW(KC_VOLD, KC_VOLU) },
    [1] =   { ENCODER_CCW_CW(KC_MPRV, KC_MNXT) },
    [2] =   { ENCODER_CCW_CW(KC_MPRV, KC_MNXT) }
};
#endif

//OLED stuff here

#ifdef OLED_ENABLE
//oled_rotation_t oled_init_user(oled_rotation_t rotation) {
//   return OLED_ROTATION_180;  // flips the display 180 degrees
//}

static void render_anim(void) {

    // Idle animation
    static const char PROGMEM idle[IDLE_FRAMES][ANIM_SIZE] = {

        {
            0,0,0,0,0,0,0,0,0,0,0,0,0,0,0,0,0,0,0,0,0,0,0,0,0,0,0,0,0,0,0,0,0,0,0,0,0,0,0,0,0,0,0,0,0,0,0,0,0,0,0,0,0,0,0,0,0,0,128,64,64,32,32,32,32,16,16,16,16,16,8,8,4,4,4,8,48,64,128,0,0,0,0,0,0,0,0,0,0,0,0,0,0,0,0,0,0,0,0,0,0,0,0,0,0,0,0,0,0,0,0,0,0,0,0,0,0,0,0,0,0,0,0,0,0,128,128,128,0,0,0,0,0,0,0,0,0,0,0,0,0,0,0,0,0,0,0,0,0,0,0,0,0,0,0,0,0,0,0,0,0,0,0,0,0,0,0,0,0,0,0,0,0,0,0,0,0,24,100,130,2,2,2,2,2,1,0,0,0,0,128,128,0,0,0,0,0,0,0,0,0,128,0,48,48,0,192,193,193,194,4,8,16,32,64,128,0,0,0,128,128,128,128,64,64,
            64,64,32,32,32,32,16,16,16,16,8,8,8,8,8,4,4,4,4,4,2,2,2,2,1,1,1,1,0,0,0,0,0,0,0,0,0,0,0,0,0,0,0,0,0,0,0,0,0,0,0,0,0,0,0,0,0,0,0,0,0,0,0,0,0,0,0,0,0,0,0,0,0,0,0,0,0,0,0,192,56,4,3,0,0,0,0,0,0,0,12,12,12,13,1,0,64,160,33,34,18,17,17,17,9,8,8,8,8,4,4,8,8,16,16,16,16,16,17,15,1,1,0,0,0,0,0,0,0,0,0,0,0,0,0,0,0,0,0,0,0,0,0,0,0,0,0,0,0,0,0,0,0,0,0,0,0,0,0,0,0,0,0,0,0,0,0,0,0,0,0,0,0,0,0,0,128,128,128,128,128,64,64,64,64,64,32,32,32,32,32,16,16,16,16,16,8,8,8,8,8,4,4,4,4,4,2,3,2,2,1,1,1,1,1,1,2,2,4,4,8,8,8,8,8,7,
            0,0,0,0,0,0,0,0,0,0,0,0,0,0,0,0,0,0,0,0,0,0,0,0,0,0,0,0,0,0,0,0,0,0,0,0,0,0,0,0,0,0,0,0,0,0,0,0,0,0,0,0,0,0,0,0,0,0,0,0,0
        },

        {
            0,0,0,0,0,0,0,0,0,0,0,0,0,0,0,0,0,0,0,0,0,0,0,0,0,0,0,0,0,0,0,0,0,0,0,0,0,0,0,0,0,0,0,0,0,0,0,0,0,0,0,0,0,0,0,0,0,0,128,64,64,32,32,32,32,16,16,16,16,16,8,8,4,4,4,8,48,64,128,0,0,0,0,0,0,0,0,0,0,0,0,0,0,0,0,0,0,0,0,0,0,0,0,0,0,0,0,0,0,0,0,0,0,0,0,0,0,0,0,0,0,0,0,0,0,128,128,128,0,0,0,0,0,0,0,0,0,0,0,0,0,0,0,0,0,0,0,0,0,0,0,0,0,0,0,0,0,0,0,0,0,0,0,0,0,0,0,0,0,0,0,0,0,0,0,0,0,24,100,130,2,2,2,2,2,1,0,0,0,0,128,128,0,0,0,0,0,0,0,0,0,128,0,48,48,0,192,193,193,194,4,8,16,32,64,128,0,0,0,128,128,128,128,64,64,
            64,64,32,32,32,32,16,16,16,16,8,8,8,8,8,4,4,4,4,4,2,2,2,2,1,1,1,1,0,0,0,0,0,0,0,0,0,0,0,0,0,0,0,0,0,0,0,0,0,0,0,0,0,0,0,0,0,0,0,0,0,0,0,0,0,0,0,0,0,0,0,0,0,0,0,0,0,0,0,192,56,4,3,0,0,0,0,0,0,0,12,12,12,13,1,0,64,160,33,34,18,17,17,17,9,8,8,8,8,4,4,8,8,16,16,16,16,16,17,15,1,1,0,0,0,0,0,0,0,0,0,0,0,0,0,0,0,0,0,0,0,0,0,0,0,0,0,0,0,0,0,0,0,0,0,0,0,0,0,0,0,0,0,0,0,0,0,0,0,0,0,0,0,0,0,0,128,128,128,128,128,64,64,64,64,64,32,32,32,32,32,16,16,16,16,16,8,8,8,8,8,4,4,4,4,4,2,3,2,2,1,1,1,1,1,1,2,2,4,4,8,8,8,8,8,
            7,0,0,0,0,0,0,0,0,0,0,0,0,0,0,0,0,0,0,0,0,0,0,0,0,0,0,0,0,0,0,0,0,0,0,0,0,0,0,0,0,0,0,0,0,0,0,0,0,0,0,0,0,0,0,0,0,0,0,0,0,0
        },

        {
            0,0,0,0,0,0,0,0,0,0,0,0,0,0,0,0,0,0,0,0,0,0,0,0,0,0,0,0,0,0,0,0,0,0,0,0,0,0,0,0,0,0,0,0,0,0,0,0,0,0,0,0,0,0,0,0,0,0,0,128,128,64,64,64,64,32,32,32,32,16,8,4,2,2,4,24,96,128,0,0,0,0,0,0,0,0,0,0,0,0,0,0,0,0,0,0,0,0,0,0,0,0,0,0,0,0,0,0,0,0,0,0,0,0,0,0,0,0,0,0,0,0,0,0,0,128,128,128,0,0,0,0,0,0,0,0,0,0,0,0,0,0,0,0,0,0,0,0,0,0,0,0,0,0,0,0,0,0,0,0,0,0,0,0,0,0,0,0,0,0,0,0,0,0,0,0,0,60,194,1,1,2,2,4,4,2,1,0,0,0,0,0,0,0,0,0,0,0,0,0,0,0,0,96,96,0,129,130,130,132,8,16,32,64,128,0,0,0,0,128,128,128,128,64,64,64,64,32,
            32,32,32,16,16,16,16,8,8,8,8,8,4,4,4,4,4,2,2,2,2,1,1,1,1,0,0,0,0,0,0,0,0,0,0,0,0,0,0,0,0,0,0,0,0,0,0,0,0,0,0,0,0,0,0,0,0,0,0,0,0,0,0,0,0,0,0,0,0,0,0,0,0,0,0,0,128,112,25,6,0,0,0,0,0,0,0,24,24,24,27,3,0,64,160,34,36,20,18,18,18,11,8,8,8,8,5,5,9,9,16,16,16,16,16,17,15,1,1,0,0,0,0,0,0,0,0,0,0,0,0,0,0,0,0,0,0,0,0,0,0,0,0,0,0,0,0,0,0,0,0,0,0,0,0,0,0,0,0,0,0,0,0,0,0,0,0,0,0,0,0,0,0,128,128,128,128,128,64,64,64,64,64,32,32,32,32,32,16,16,16,16,16,8,8,8,8,8,4,4,4,4,4,2,3,2,2,1,1,1,1,1,1,2,2,4,4,8,8,8,8,8,7,0,0,0,
            0,0,0,0,0,0,0,0,0,0,0,0,0,0,0,0,0,0,0,0,0,0,0,0,0,0,0,0,0,0,0,0,0,0,0,0,0,0,0,0,0,0,0,0,0,0,0,0,0,0,0,0,0,0,0,0,0,0
        },
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

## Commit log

2022-03-13 Kicad setup and added submodules
    [litl.kicad_pcb, litl.kicad_sch]
2022-03-13 Start of matrix
    [litl.kicad_sch]
2022-03-13 Schematic complete
    [litl.kicad_pcb, litl.kicad_sch]
2022-03-22 Footprints placed
    [litl.kicad_pcb]
2022-03-23 Diode layout complete
    [litl.kicad_pcb, litl.kicad_sch]
2022-03-23 Vias added
    [litl.kicad_pcb, litl.kicad_sch]
2022-04-08 Tracks done
    [litl.kicad_pcb, litl.kicad_sch]
2022-04-08 Mounting holes and ground fill done
    [litl.kicad_pcb]
2022-04-09 Plate and Base added
    [litl_base.kicad_pcb, litl_base.kicad_sch, litl_base_plate.kicad_pcb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]
2022-04-10 Base and plates reworked
    [litl_base.kicad_pcb, litl_base.kicad_sch, litl_base_plate.kicad_pcb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]
2022-04-11 Minimised base size and shrunk top of PCB to make it under 100mm. Send to fab
    [litl-B_Cu.gbl, litl-B_Mask.gbs, litl-B_Paste.gbp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]
2022-04-26 1.5u footprint fixed
2022-05-04 Build guide link added
    [litl_plate-Edge_Cuts.dxf]
2022-06-07 Firmware added
    [litl-B_Cu.gbl, litl-B_Mask.gbs, litl-B_Paste.gbp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]
2022-06-27 v2 boards done and test OLED firmware added
    [litl-B_Cu.gbl, litl-B_Mask.gbs, litl-B_Paste.gbp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]
2022-06-29 Updated OLED direction
    [litl-B_Cu.gbl, litl-B_Mask.gbs, litl-B_Paste.gbp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]
2022-07-18 V2 gerbers for production
    [litl-B_Cu.gbl, litl-B_Mask.gbs, litl-B_Paste.gbp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]
2022-11-14 Firmware files refreshed
    [Acrylic Guard-Edge_Cuts.dxf, Acrylic Guard.kicad_pcb, Acrylic Guard.kicad_sch]
2022-12-13 Updated silkscreening on board and switch socket option added for encoders. Gerbers v2.1 added
    [litl-B_Cu.gbl, litl-B_Mask.gbs, litl-B_Paste.gbp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]
2023-01-10 Updated rotary encoder direction in vial firemware files
2023-01-26 Plate file rebuilt and made cleaner. New plate gerbers
    [litl_plate-B_Cu.gbl, litl_plate-B_Cu.gbr, litl_plate-B_Mask.gbr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]
2023-04-30 Litl v3 created
    [litl-B_Cu.gbl, litl-B_Mask.gbs, litl-B_Paste.gbp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]
2023-04-30 V3 tweaks and new images
    [litl-B_Cu.gbl, litl-B_Mask.gbs, litl-B_Paste.gbp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]
2025-03-20 New base progress
    [litl_base-B_Cu.gbl, litl_base-B_Mask.gbs, litl_base-B_Paste.gbp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]
2025-03-21 New base 2025 gerbers added
    [litl_base-B_Cu.gbl, litl_base-B_Mask.gbs, litl_base-B_Paste.gbp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]

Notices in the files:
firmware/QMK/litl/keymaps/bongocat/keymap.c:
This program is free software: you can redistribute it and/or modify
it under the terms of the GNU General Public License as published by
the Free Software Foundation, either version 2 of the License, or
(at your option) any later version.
